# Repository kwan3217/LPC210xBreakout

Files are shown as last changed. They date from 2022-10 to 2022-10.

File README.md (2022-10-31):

# LPC210xBreakout
Breakout board for NXP LPC2101/2/3 microcontroller. The pinout for the crystals and power is similar enough to that of an LPC2104/5/6 that it will
probably work for that chip as well.

# How to use
All 48 pins on the chip are broken out to their respective pins on the board. Digital grounds (3 pins) are connected together. Several pins are connected to each other through default-shorted jumpers. If you wish, you can cut the jumpers with a razor blade.

 * Analog ground (pin 31) to digital ground
 * Analog power (pin 42) to digital I/O (3.3V) power
 * RTC power (pin 4) to digital I/O (3.3V) power

The chip uses a 1.8V core voltage, and needs both 3.3V and 1.8V to operate. I have included a 3.3->1.8V regulator on the board. Since the 1.8V supply pin is broken out, you don't have to use this regulator if you don't want -- just don't populate the regulator.

# Interesting things and oddities
The board file has the footprint for a TSSOP-16 and a TSSOP-20 chip. These footprints are outside of the board outline, and are there so that the stencil
I make also has those footprints, for another project I am working on.

# Getting this board
I recommend getting the board from https://oshpark.com/shared_projects/SdR4aknh. There isn't an explicit bill of materials. Instead, the bill of materials is encoded in the schematic (.kicad_sch) file. Each component has either a Digikey or Mouser part number -- use those for generating your own bill of materials. If those exact parts aren't available (Darn chip shortage!) you are on your own, but those numbers should still lead you to the specifications for the given parts, so you can pick substitutes.

# How to modify
This board is Open Hardware, licensed under the GPL 3.0 license. That's the legal part. My intent is that:
 * You can make as many exact copies of the board as you wish, including with my StKwan logo. The link at oshpark.com is a good place to do that.
 * You may modify the board as you wish, but if you do so, please remove my StKwan logo from the board. If you are modifying it, you should take pride in your work and put your name on it anyway.
   * It's fine if the _only_ modification you make to the board is to put your name on it. Take my logo off in that case, too.
 * Follow the rest of the GPL as concerning share-alike, etc.
 * The only reason I am licensing the board at all is so I can put the OSHW logo on the board.

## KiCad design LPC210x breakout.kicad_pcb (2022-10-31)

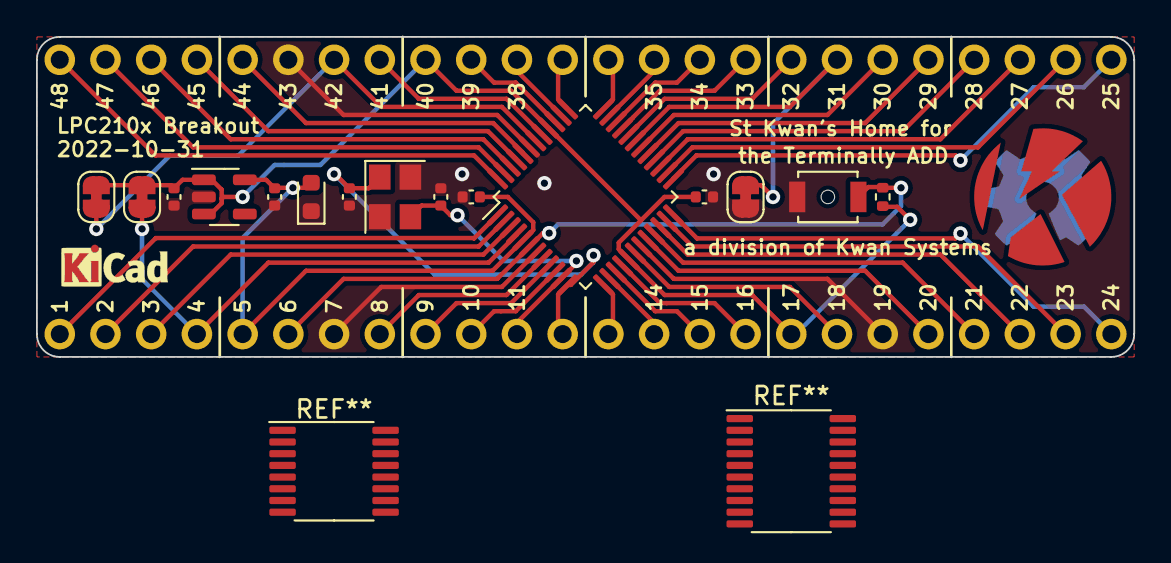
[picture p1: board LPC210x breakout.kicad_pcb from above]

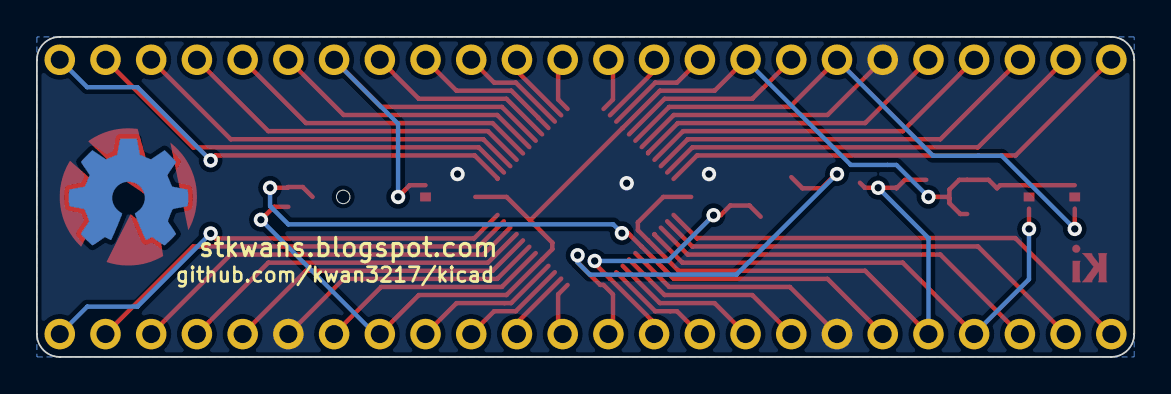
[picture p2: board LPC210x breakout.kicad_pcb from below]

Board: 2 copper layers, 61.0 x 17.8 mm, 20 parts (3 on the bottom side), 45 nets.

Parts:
C105, C117, C201, C205: 1uF; C_0402_1005Metric
C111, C112: 22pF; C_0402_1005Metric
D201: RED; LED_0603_1608Metric
G101: KwanSystems; StKwansSoldermask
G102: DesignedWithKicad; Symbol_KiCAD-Logo_CopperAndSilkScreenTop_small
G103: OSHW; OSHW-Symbol_6.7x6mm_SolderMask
J101, J102: Conn_01x24_Male; PinHeader_1x24_P2.54mm_Vertical
JP104: VBAT; SolderJumper-2_P1.3mm_Bridged_RoundedPad1.0x1.5mm
JP131: AnalogGround; SolderJumper-2_P1.3mm_Bridged_RoundedPad1.0x1.5mm
JP142: VDDA; SolderJumper-2_P1.3mm_Bridged_RoundedPad1.0x1.5mm
R106: 10k; R_0402_1005Metric
S106: B3U-1000; SW_SPST_B3U-1000P-B
U101: LPC2103; LQFP-48_7x7mm_P0.5mm
U201: TCR2EF 1.8V; SOT-23-5
Y101: 12MHz; Crystal_SMD_Abracon_ABM8G-4Pin_3.2x2.5mm

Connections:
+1V8: C105.1, C205.1, D201.2 (A), J101.5, U101.5 (VDD(1V8)), U201.5 (OUT)
+3V3: C117.1, C201.1, J101.17, J102.16, JP104.1 (A), JP142.1 (A), R106.2, U101.17 (VDD(3V3)), U101.40 (VDD(3V3)), U201.1 (IN), U201.3 (EN)
/P01: J101.1, U101.1 ((MAT1.2/MISO1)P0.19)
/P02: J101.2, U101.2 ((MAT1.3/MOSI1)P0.20)
/P03: J101.3, U101.3 ((SSEL1/MAT3.0)P0.21)
/P04: J101.4, JP104.2 (B), U101.4 (VBAT)
/P06: J101.6, R106.1, S106.2 (B), U101.6 (~RST)
/P08: J101.8, U101.8 ((~TRST/CAP2.0)P0.27)
/P09: J101.9, U101.9 ((TMS/CAP2.1)P0.28)
/P10: J101.10, U101.10 ((TCK/CAP2.2)P0.29)
/P11: C111.2, J101.11, U101.11 (XTAL1), Y101.3
/P12: C112.2, J101.12, U101.12 (XTAL2), Y101.1
/P13: J101.13, U101.13 ((TXD0/MAT3.1)P0.0)
/P14: J101.14, U101.14 ((RXD0/MAT3.2)P0.1)
/P15: J101.15, U101.15 ((TDI/MAT3.3)P0.30)
/P16: J101.16, U101.16 ((TDO)P0.31)
/P18: J101.18, U101.18 ((SCL0/CAP0.0)P0.2)
/P20: J101.20, U101.20 (RTCX1)
/P21: J101.21, U101.21 ((SDA0/MAT0.0)P0.3)
/P22: J101.22, U101.22 ((SCK0/CAP0.1)P0.4)
/P23: J101.23, U101.23 ((MISO0/MAT0.1)P0.5)
/P24: J101.24, U101.24 ((MOSI0/CAP0.2)P0.6)
/P25: J102.1, U101.25 (RTCX2)
/P26: J102.2, U101.26 (RTCK)
/P27: J102.3, U101.27 (DBGSEL)
/P28: J102.4, U101.28 ((SSEL0/MAT2.0)P0.7)
/P29: J102.5, U101.29 ((TXD1/MAT2.1)P0.8)
/P30: J102.6, U101.30 ((RXD1/MAT2.2)P0.9)
/P32: J102.8, U101.32 ((AD0.0)P0.22)
/P33: J102.9, U101.33 ((AD0.1)P0.23)
/P34: J102.10, U101.34 ((AD0.2)P0.24)
/P35: J102.11, U101.35 ((RTS1/CAP1.0/AD0.3)P0.10)
/P36: J102.12, U101.36 ((CTS1/CAP1.1/AD0.4)P0.11)
/P37: J102.13, U101.37 ((DSR1/MAT1.0/AD0.5)P0.12)
/P38: J102.14, U101.38 ((AD0.6)P0.25)
/P39: J102.15, U101.39 ((AD0.7)P0.26)
/P41: J102.17, U101.41 ((DTR1/MAT1.1)P0.13)
/P42: J102.18, JP142.2 (B), U101.42 (VDDA)
/P44: J102.20, U101.44 ((DCD1/SCK1/EINT1)P0.14)
/P45: J102.21, U101.45 ((RI1/EINT2)P0.15)
/P46: J102.22, U101.46 ((EINT0/MAT0.2)P0.16)
/P47: J102.23, U101.47 ((CAP1.2/SCL1)P0.17)
/P48: J102.24, U101.48 ((CAP1.3/SDA1)P0.18)
GND: C105.2, C111.1, C112.1, C117.2, C201.2, C205.2, D201.1 (K), J101.7, J101.19, J102.19, JP131.1 (A), S106.1 (A), U101.7 (VSS), U101.19 (VSS), U101.43 (VSS), U201.2 (GND), Y101.2, Y101.4
GNDA: J102.7, JP131.2 (B), U101.31 (VSSA)
